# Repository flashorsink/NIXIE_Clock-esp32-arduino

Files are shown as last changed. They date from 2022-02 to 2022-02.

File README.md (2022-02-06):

# NIXIE_Clock-esp32-arduino
使用esp32，8管，自动休眠、氛围灯、休眠和唤醒动画、音乐闹钟、基于Blinker的蓝牙控制  

<p float="left">
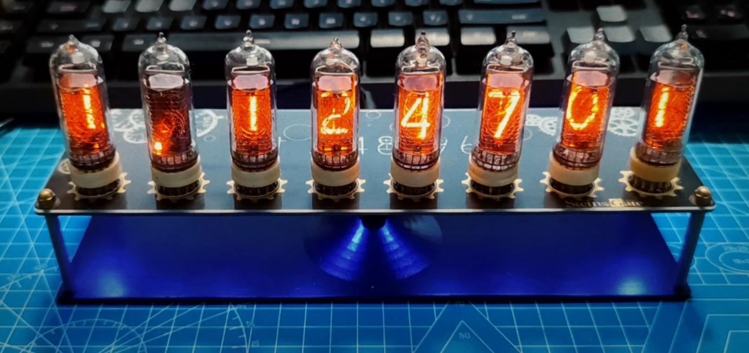
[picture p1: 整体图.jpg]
  
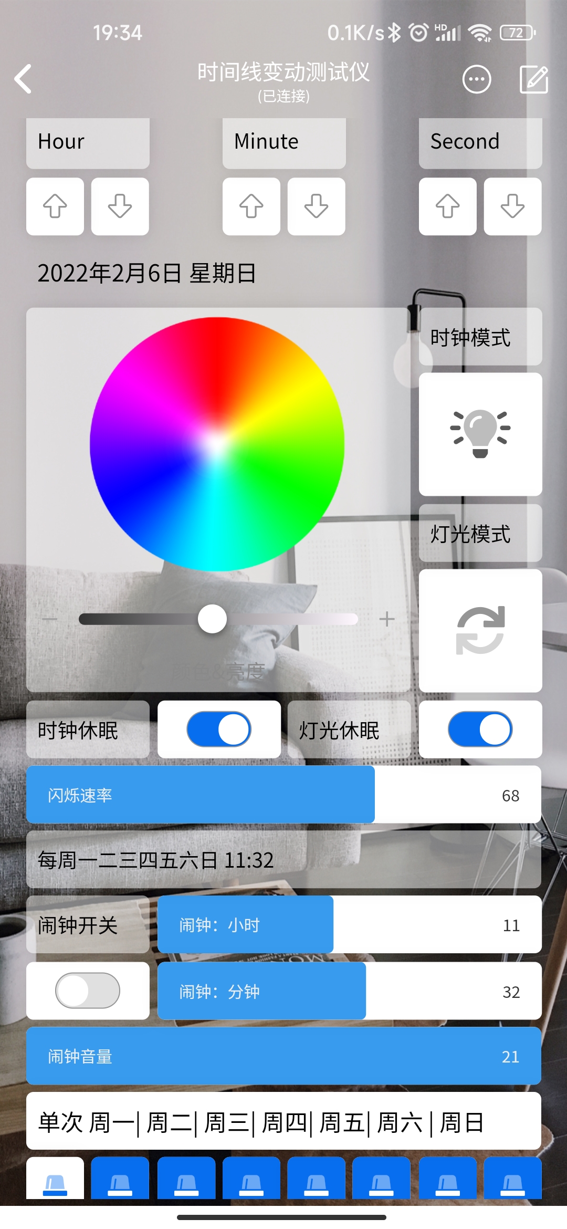
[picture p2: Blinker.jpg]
   
</p>

演示视频https://www.bilibili.com/video/BV1Kr4y1h7Qn/

## 程序

本程序使用esp32 arduino，请使用1.0.6版本，2.0.0及以上版本不兼容无法编译

有两处需要修改部分参见esp32代码libraries文件夹中的说明

各项设置断电后仍会保存

闹钟只支持mp3文件放在sd卡根目录下，可放置多个音乐，每一次响铃会改变歌曲

## PCB

全触摸设计，正面盖板没有开孔，电源口居中，辉光管可插拔设计便于移动和更换。

音频芯片TQFN不易焊接，制作部分用了嘉立创SMT，库中有此芯片的装贴。

## 亚克力

亚克力盖板厚度应小于1mm，否则会影响触摸按键效果

## 底座

底座为3D打印，需要一定精度打印M3螺纹，铜柱高度为40mm

## Blinker

APP蓝牙控制，使用方式在Blinker文件夹中说明

## 操作
各项设置与闹钟时间断电后仍会保留
触摸包含两个控制触摸按键和一个电源触摸按键
1. 短按：设置分钟
2. 长按：设置小时
3. 同时短按：改变时钟模式，四种模式包括时钟显示、时间线时钟显示和时间线随机显示
4. 同时长按：改变灯光模式，包括单色显示、呼吸、渐变、七彩，切换和唤醒都有过渡动画
5. 当闹铃响起时触摸任意一个控制触摸按键都将关闭闹铃

## 注意安全
辉光管使用170v电压，虽然使用的是12VDC转170VDC电流较小并设计了自恢复保险丝，但仍需要注意用电安全，不要触摸辉光钟引脚及PCB底面。

## 感谢
https://github.com/zer0pwned/NixieTubeClock 提供了最初版本的灵感，并使用了其中的辉光插座、时钟芯片和继电器的元件库

https://github.com/Sadudu/MAX1771 提供了12V-170V DC-DC升压电路，经测试输出电容改为电解电容可避免啸叫

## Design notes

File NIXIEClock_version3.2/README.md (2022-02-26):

## esp32 为 esp32-wroom-32(4MB) esp32-wroom-32D也可以，辉光管为in-14
## TP1是170V升压电路的使能，为了测试其他元件时断开使用的，使用时需焊起来
## BOM添加说明：L3与L4用焊锡连通，C33和C34不焊接。此为预留滤波电路，经过测试可以不使用
## SD卡用作闹钟音乐，可放置多首歌每次响铃会切换，仅支持mp3
## 烧录指南
<p float="left">
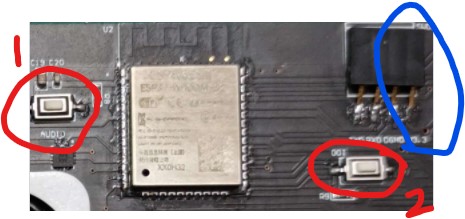
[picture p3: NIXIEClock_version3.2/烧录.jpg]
  
</p>

1. 通电烧录时使用usb转串口连接RXD、TXD、GND三线并给总电源通电，并打开总电源触摸开关，蓝圈的3.3V不使用

2. 红圈1为esp32的使能，2为esp32的IO0，烧录时先同时按下按键1和按键2，然后先松开按键2再松开按键1，此时esp32进入烧录模式

3. 烧录
 
4. 烧录完成后按按键1并松开，程序运行

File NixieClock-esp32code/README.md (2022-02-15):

## 22.2.15更新
  使用多天后发现有触摸误触发的可能，更新每天晚上三点会刷新触摸按键数值避免误触发，触摸触发值+1
  blinker闹钟时间反馈格式优化
## 烧录时需选择Huge APP模式上传，否则会报容量不足的错

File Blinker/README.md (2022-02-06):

# APP使用方法

1. 下载[Blinker app](https://diandeng.tech/doc/app-download)，制作时使用的是2.5.7版本
2. 注册登录
3. 确保辉光钟已开启
4. 点击右上角加号-独立设备-蓝牙接入-选择你的设备点击接入
5. 在设备界面内，点击右上角三点-界面配置-将“Blinker界面配置”文件中的全部复制粘贴-更新配置
6. 更新配置后界面不会立刻改变，退出到所有设备重新打开即可

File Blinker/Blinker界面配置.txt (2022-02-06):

{¨config¨{¨headerColor¨¨transparent¨¨headerStyle¨¨dark¨¨background¨{¨img¨¨assets/img/bg/f1.jpg¨¨isFull¨»}}¨dashboard¨|{¨type¨¨ran¨¨t0¨¨闹钟音量¨¨clr¨¨#389BEE¨¨max¨¤L¨min¨É¨bg¨É¨cols¨Ñ¨rows¨Ê¨key¨´v´´x´É´y´¤F¨speech¨|÷¨lstyle¨Ì}{ßA¨btn¨¨ico¨¨fal fa-arrow-alt-up¨¨mode¨ÊßC¨文本1¨¨t1¨¨文本2¨ßIÉßJÊßKÊßL¨su¨´x´Ï´y´ËßM|÷ßNÍ}{ßAßOßP¨fal fa-arrow-alt-down¨ßRÊßCßSßTßUßIÉßJÊßKÊßL¨hd¨´x´Ê´y´ËßM|÷ßNÍ}{ßAßOßPßQßRÊßCßSßTßUßIÉßJÊßKÊßL¨hu¨´x´É´y´ËßM|÷ßNÍ}{ßAßOßPßWßRÊßCßSßTßUßIÉßJÊßKÊßL¨md¨´x´Í´y´ËßM|÷ßNÍ}{ßAßOßPßQßRÊßCßSßTßUßIÉßJÊßKÊßL¨mu¨´x´Ì´y´ËßM|÷ßNÍ}{ßAßOßPßWßRÊßCßSßTßUßIÉßJÊßKÊßL¨sd¨´x´Ð´y´ËßM|÷ßNÍ}{ßA¨tex¨ßC¨Hour¨ßTßU¨size¨¤EßIÊßP´´ßJËßKÊßLßT´x´É´y´ÊßM|÷}{ßAßcßC¨Minute¨ßTßUße¤EßIÊßP´´ßJËßKÊßL¨t2¨´x´Ì´y´ÊßM|÷}{ßAßcßC¨Second¨ßTßUße¤EßIÊßP´´ßJËßKÊßL¨t3¨´x´Ï´y´ÊßM|÷}{ßAßOßP¨fad fa-sync¨ßRÊßC´´ßTßUßIÉßJËßKËßL¨rm¨´x´Ï´y´ÑßM|÷ßNÉ}{ßAßcßC¨时钟休眠¨ßTßUße¤EßIÊßP´´ßJËßKÊßL¨tex-cjz¨´x´É´y´¤AßM|÷}{ßAßOßP¨fal fa-power-off¨ßRÊßCßSßTßUßIÉßJËßKÊßL¨as¨´x´É´y´¤EßM|÷ßNÌßE¨#076EEF¨}{ßAßOßP¨fad fa-toggle-on¨ßRÊßCßSßTßUßIÉßJËßKÊßL¨sw¨´x´É´y´ÉßM|÷ßNÌ}{ßAßcßC¨更改日期/时间¨ßTßUße¤EßIËßP´´ßJÍßKÊßL¨tex-hj4¨´x´Ë´y´ÉßM|÷ßNÊ}{ßAßcßC´´ßTßUße¨16¨ßIËßP´´ßJÑßKÊßL´d´´x´É´y´ÌßM|÷ßNÎ}{ßAßcßC¨闹钟开关¨ßTßUße¤EßIÊßP´´ßJËßKÊßL¨tex-eyf¨´x´É´y´¤DßM|÷ßNÉ}{ßAßcßC¨灯光休眠¨ßTßUße¤EßIÊßP´´ßJËßKÊßL´´´x´Í´y´¤AßM|÷}{ßAßOßPßnßRÊßC¨自动休眠¨ßTßUßIÉßJËßKÊßL¨sc¨´x´Ë´y´¤AßM|÷ßNÌßEßp}{ßAßOßP¨fad fa-siren¨ßRÉßCßSßTßUßIÉßJÊßKÊßL´w´´x´Ì´y´¤HßM|÷ßNÍßEßp}{ßAßOßPß10ßRÉßC´周一´ßTßUßIÉßJÊßKÊßL´f´´x´Î´y´¤HßM|÷ßNÍßEßp}{ßAßOßPß10ßRÉßCßSßTßUßIÉßJÊßKÊßL´T´´x´Í´y´¤HßM|÷ßNÍßEßp}{ßAßOßPß10ßRÉßCßSßTßUßIÉßJÊßKÊßL´t´´x´Ë´y´¤HßM|÷ßNÍßEßp}{ßAßOßPß10ßRÉßC´7´ßTßUßIÉßJÊßKÊßL´S´´x´Ð´y´¤HßM|÷ßNÍßEßp}{ßAßOßPß10ßRÉßCßSßTßUßIÉßJÊßKÊßL´m´´x´Ê´y´¤HßM|÷ßNÍßEßp}{ßAßOßPß10ßRÉßCßSßTßUßIÉßJÊßKÊßL´s´´x´Ï´y´¤HßM|÷ßNÍßEßp}{ßAßBßC¨闹钟：小时¨ßEßFßG¤OßHÉßIÉßJÏßKÊßL´ah´´x´Ë´y´¤DßM|÷ßNÎ}{ßAßBßC¨闹钟：分钟¨ßEßFßG¤xßHÉßIÉßJÏßKÊßL´am´´x´Ë´y´¤EßM|÷ßNÎ}{ßAßcßC¨单次 周一|  周二|  周三| 周四|  周五| 周六 | 周日   ¨ßTßUßeßußIÉßP´´ßJÑßKÊßL¨tex-vka¨´x´É´y´¤GßM|÷ßNÎ}{ßAßOßP¨fad fa-lightbulb-on¨ßRÉßC´´ßTßUßIÉßJËßKËßL´cm´´x´Ï´y´ÎßM|÷ßNÉßE¨#595959¨}{ßAßBßC¨闪烁速率¨ßEßFßG¢1cßHÊßIÉßJÑßKÊßL´rs´´x´É´y´¤BßM|÷ßNÌ}{ßAßcßC´´ßT´´ße¤EßIÊßP´´ßJÑßKÊßL´al´´x´É´y´¤CßM|÷ßNÎ}{ßAßOßPß10ßRÊßCßSßTßUßIÉßJÊßKÊßL´ss´´x´É´y´¤HßM|÷ßNÍßEßp}{ßA¨col¨ßC¨颜色&亮度¨ßEßFßIÊßJÏßKÏßL¨RGB¨´x´É´y´ÍßM|÷}{ßAßOßPßnßRÊßCßSßTßUßIÉßJËßKÊßL´ls´´x´Ï´y´¤AßM|÷ßNÌßEßp}{ßAßcßC¨灯光模式¨ßTßUße¤EßIÊßP´´ßJËßKÊßL¨tex-r4w¨´x´Ï´y´ÐßM|÷}{ßAßcßC¨时钟模式¨ßTßUße¤EßIÊßP´´ßJËßKÊßL¨tex-66x¨´x´Ï´y´ÍßM|÷}÷¨actions¨|¦¨cmd¨¦¨switch¨‡¨text¨‡´on´¨打开?name¨¨off¨¨关闭?name¨—÷¨triggers¨|{¨source¨ß1H¨source_zh¨¨开关状态¨¨state¨|´on´ß1K÷¨state_zh¨|´打开´´关闭´÷}÷}

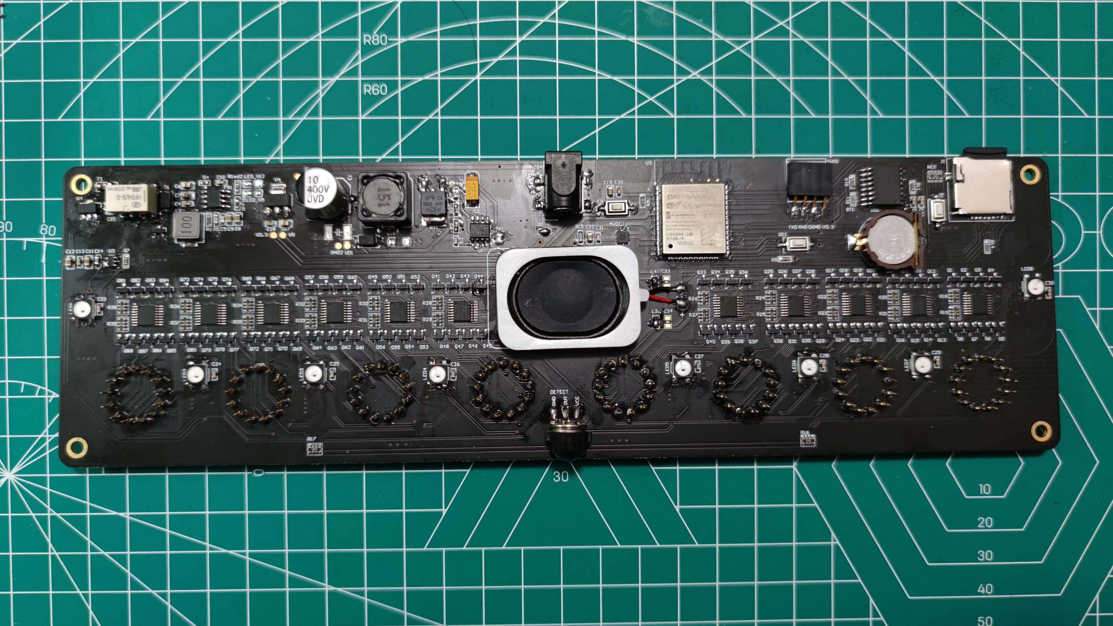
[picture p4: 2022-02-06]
背面图_1.jpg

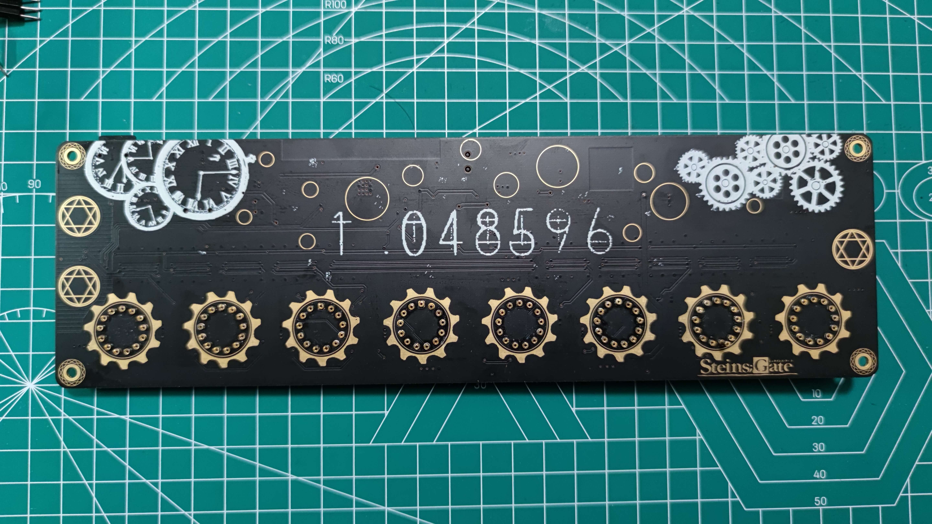
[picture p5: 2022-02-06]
正面图_1.jpg

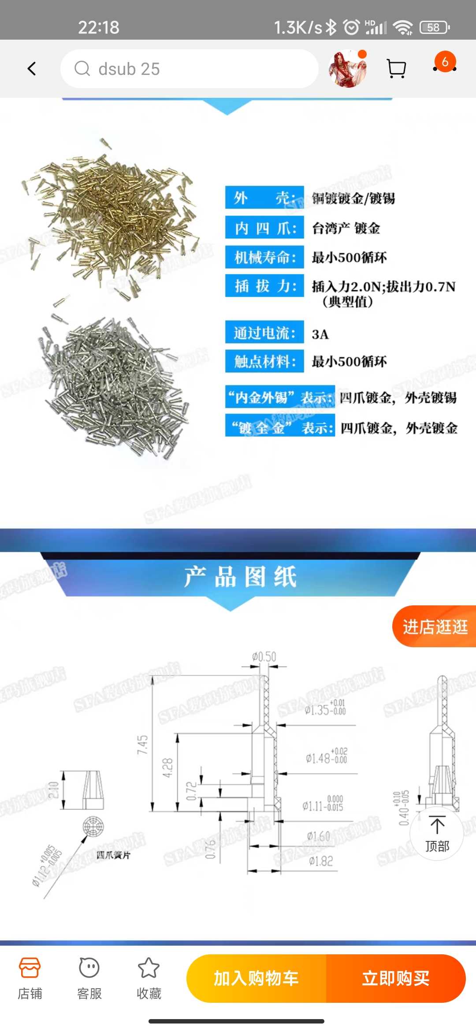
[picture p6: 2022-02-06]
NIXIEClock_version3.2/镀金插针_需要13x8x2=208个.jpg

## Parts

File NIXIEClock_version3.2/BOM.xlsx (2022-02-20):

Comment | Description | Designator | Footprint | LibRef | Quantity
MAX98357 | 音频芯片 | AUDIO | QFN16_3X3 | MAX98357 | 1
beep | 4Ω 3W 25*35*6.6 | beep | BEEP2 | beep | 1
CR1220 holder | 电池底座 | BT1 | BAT1220 | BATTERY | 1
100u/16v | 贴片钽电容 | C2 | CD C(6032) | C-CD | 1
0.1uF | 无极性贴片电容 | C3, C4, C10, C13, C18, C20, C21, C22, C23, C24, C25, C26, C27, C28, C29, C30, C31 | C 0603_L | C | 17
100pF | 无极性贴片电容 | C5 | C 0603_L | C | 1
10uF | 无极性贴片电容 | C6, C7, C11, C12, C15, C17, C19, C32 | C 0805_L | C | 8
22uF | 无极性贴片电容 | C8, C9 | C 0805_L | C | 2
20pf | 无极性贴片电容 | C14 | C 0603 | C | 1
220pF（不焊接！） | 无极性贴片电容 | C33, C34 | C 0805_L | C | 2
3.5*1.3 | 低压电源接口 | CON1 | DC-050 | P-DC | 1
1N4007(M7) | 1 Amp General Purpose Rectifier | D1 | 1N4007W | Diode 1N4007 | 1
RDB223 | 数字热释电传感器 | DETECT | 红外热释电 | UGN3503 | 1
DS3231 | 时钟芯片 | DS1 | SOP16_75MM | DS3231 | 1
10uF/400V | 贴片电解电容 | E1 | CM F(10*10.2) | C-CM | 1
SW-PB | Switch | EN, IO0, S1 | 贴片按键（红头） | SW-PB | 3
3A | 贴片保险丝 | F1 | FU 1206 | FU | 1
FR9886 2.5A | 2.5A DC-DC | FR1 | SOP8_N | FR9833 | 1
74HC595 | 8位移位寄存器 | IC1, IC2, IC3, IC4, IC5, IC6, IC7, IC8, IC9, IC10, IC11 | TSSOP16_N | 74HC595 | 11
Micro SD | Micro SD卡 | J1 | Micro SD | Micro SD | 1
150uf | 功率屏蔽电感 | L1 | CDRH127 | L-CDRH | 1
10uH | 功率屏蔽电感 | L2 | L-SMD-0630 | L-CDRH | 1
10uH(直接用焊锡连通！) | 小功率贴片电感 | L3, L4 | L 0805_L | L | 2
WS2812B | LED | LED1, LED2, LED3, LED4, LED5, LED6, LED7, LED8 | WS2812B-5050 | WS2812B | 8
绿色 | 贴片LED(测试使用) | LED_V5 | LED 0805G | LED-SMD | 1
蓝色 | 贴片LED(测试使用) | LED_V12 | LED 0805B | LED-SMD | 1
MMBTA42 | 高频放大-NPN型 | Q1, Q2, Q3, Q4, Q5, Q6, Q7, Q8, Q9, Q10, Q11, Q12, Q13, Q14, Q15, Q16, Q17, Q18, Q19, Q20, Q21, Q22, Q23, Q24, Q25, Q26, Q27, Q28, Q29, Q30, Q31, Q32, Q33, Q34, Q35, Q36, Q37, Q38, Q39, Q40, Q41, Q42, Q43, Q44, Q45, Q46, Q47, Q48, Q49, Q50, Q51, Q52, Q53, Q54, Q55, Q56, Q57, Q58, Q59, Q60, Q61, Q62, Q63, Q64, Q65, Q66, Q67, Q68, Q69, Q70, Q71, Q72, Q73, Q74, Q75, Q76, Q77, Q78, Q79, Q80, Q81, Q82, Q83, Q84, Q85, Q86, Q87, Q88 | SOT23-3N | 8050-SMD | 88
S9013 | NPN Bipolar Transistor | QN | SOT23-3L | NPN | 1
IRFR224 | N沟场效应管 | QT1 | TO252 | IRF3710 | 1
0 | 贴片电阻 | R0 | R 0603 | R | 1
50m | 贴片电阻 | R1 | R 0805_L | R | 1
1.8M/0603/1% | 贴片电阻 | R2 | R 0603 | R | 1
16K/0603/1% | 贴片电阻 | R3 | R 0603 | R | 1
100K | 贴片电阻 | R4 | R 0603_L | R | 1
44.2K | 贴片电阻 | R5 | R 0603 | R | 1
10K | 贴片电阻 | R6, R8, R9, R12, R14 | R 0603 | R | 5
10k | 贴片网络排阻 | R13, R10, R11 | RCA-8P4R-0603 | R-8P4R | 1
1M | 贴片电阻 | R15 | R 0603 | R | 1
20K | 贴片网络排阻 | R16, R17 | RCA-8P4R-0603 | R-8P4R | 2
1k | 贴片网络排阻 | R18, R19, R20, R21, R22, R23, R24, R25, R26, R27, R28, R29, R30, R31, R32, R33, R34, R35, R36, R37, R38, R39, R7 | RCA-8P4R-0603 | R-8P4R | 22
RFD4/5V | 继电器 | Relay1 | HFD4 | Relay | 1
180 | 贴片电阻 | Rled1 | R 0603 | R | 1
820 | 贴片电阻 | Rled2 | R 0603 | R | 1
Header 4 | Header, 4-Pin | SWD1 | HDR2.54-M-WS-4P | Header 4 | 1
铜柱 | 40mm | T0, T1, T2, T3 | 铜柱_六芒星 | 铜柱 | 4
MAX1771 | 170V升压芯片 | U1 | SOP8_M | MAX1771 | 1
ESP32-WROOM-32D | IC: SoC; GPIO, I2C, I2S, IR, SD, SDIO, SPI, UART; 2.7Ã·3.6VDC; 20dBm | U2 | *MODULE_ESP32-WROOM-32D | ESP32-WROOM-32D | 1
ttp223 | 触摸芯片 | U3 | SOT23-6L | ttp223 | 1
HT7150 | LDO线性稳压芯片 | U4 | SOT89_M | HT71xx | 1
AMS1117-3V3 | 三端稳压芯片 | V4 | SOT223_N | AMS1117 | 1
>1A 400V（RS1G） | 肖特基二极管 | VD1 | SMA | （RS1G） | 1

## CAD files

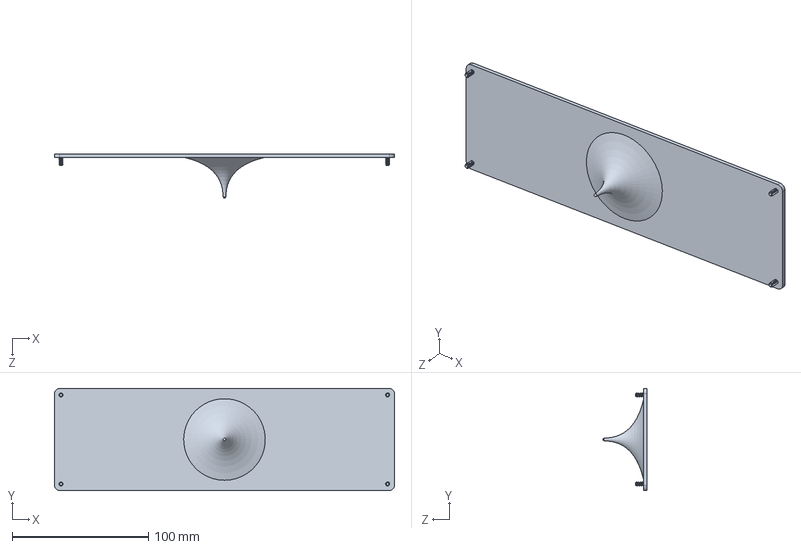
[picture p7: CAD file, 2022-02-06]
亚克力盖板及底座模型/底座.SLDPRT
250.0 x 75.0 x 32.5 mm

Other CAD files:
亚克力盖板及底座模型/亚克力盖板.DWG
亚克力盖板及底座模型/底座.STL

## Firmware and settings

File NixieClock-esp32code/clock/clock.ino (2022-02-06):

//#define TEST
#ifdef TEST
    #define SLEEPTIME 100
#else
#define SLEEPTIME 1200
#endif
#include<string.h>
#include<stdio.h>
char str[50];
char str2[4];
/////////////////// data storage configuration/////////////////////////////
#include <Preferences.h>
Preferences STORGE; 
///////////////////DS3231 configuration///////////////////////
#include <Wire.h> // must be included here so that Arduino library object file references work
#include <RtcDS3231.h>
#define RtcSquareWavePin 5 //alarm pin
#define countof(a) (sizeof(a) / sizeof(a[0]))
RtcDS3231<TwoWire> Rtc(Wire);//SDA21 SCL22
volatile bool interruptFlag = false;//alarm interrupt
RtcDateTime oldtime;
RtcDateTime now;
bool flashnow=true;
///////////////////Scan configuration/////////////////////
#define SCAN  34//18
//////////////////Ticker clock configuration///////////////////////////
#include <Ticker.h>
Ticker tickerclock;
Ticker tickerchange;
volatile bool timetoflash = false;
bool clockflag=false;
volatile int clock_counter=0;
bool scanhuman=true;
///////////////////RGB configuration///////////////////////////
volatile int8_t gradient=0;//0 means nothing;1 means changemode-1 light down;2 means changemode light up;3 means changemode light down;
#include "Freenove_WS2812_Lib_for_ESP32.h"
#define LEDS_COUNT  8 //how many led 
#define LEDS_PIN  12
#define CHANNEL   0
Freenove_ESP32_WS2812 strip = Freenove_ESP32_WS2812(LEDS_COUNT, LEDS_PIN, CHANNEL, TYPE_GRB);
//bool rgb_switch=false;
bool rgb_sleep=false;
uint8_t color_r=0,color_g=0,color_b=0,bright=0;
int8_t RGBmode=1;
bool RGBflag=false;
Ticker tickerRGB;
//////////////////Touch configuration//////////////////////
Ticker tickertouch;
int8_t gottouch1=0;
int8_t gottouch2=0;
#define TOUCHPAD_1 T3//gpio13
#define TOUCHPAD_2 T4//gpio15

int8_t level_1; // 
int8_t level_2; // 

#define TOUCH1 1
#define TOUCH2 2
#define BOTHTOUCH_SHORT 3
#define BOTHTOUCH_LONG 4
#define TOUCH1_LONG 5
#define TOUCH2_LONG 6
bool touch1=false;
bool touch2=false;
bool touchdone=false;//indicate if finger has moed away 
int  touch=0; //1:button1 2:botton2 3:botton 1and2 short 4:botton 1 and 2 long
///////////////////music configuration///////////////////////
#include "Audio.h"
#include "SPI.h"
#include "SD.h"
#include "FS.h"
#define SD_CS         4
#define SPI_MOSI      23
#define SPI_MISO      19
#define SPI_SCK       18
#define I2S_DOUT      25
#define I2S_BCLK      27
#define I2S_LRC       26
Audio audio;
char songname[20][50];
int songnumber=0;
volatile bool songflag=false;
bool songon=false;
//////////////////////74hc595 confifuration////////////////////
unsigned char LED_0F[] = 
    {
        B10000000,B00000000,//0
    	B00000000,B01000000,//1
        B00000000,B10000000,//2
        B00000001,B00000000,//3
        B00000010,B00000000,//4
        B00000100,B00000000,//5 
        B00001000,B00000000,//6
        B00010000,B00000000,//7
        B00100000,B00000000,//8
        B01000000,B00000000,//9
        B00000000,B00100000,//.
        B00000000,B00000000,//none
        B10000000,B00000000,//0
    	B00000000,B01000000,//1
        B00000000,B10000000,//2
        B00000001,B00000000,//3
        B00000010,B00000000,//4
        B00000100,B00000000,//5 
        B00001000,B00000000,//6
        B00010000,B00000000,//7
        B00100000,B00000000,//8
        B01000000,B00100000,//9+.
    };
#define NONE 11
#define DOT 10
    unsigned char LED[8]={11,11,11,11,11,11,11,11};//cache for 8 figures initial none
    int SCLK = 14;
    int RCLK = 17;
    int DIO = 16; 
int8_t clockmode=1;
//////////////////////ALARM ////////////////////////////////
   bool alarmswitch,alarmsingle;
   bool day[7];
   int8_t alarmh,alarmm;
//////////////////////blinker configuration/////////////////////

#define BLINKER_BLE  
#define BLINKER_PRINT Serial
#include "Blinker.h"
int32_t voice=5;
bool switchset=0;
BlinkerRGB RGB("RGB");
//BlinkerButton RGBS_SWITCH("cs");
BlinkerButton RGBS_SLEEP("ls");
BlinkerButton HOUR_UP("hu");
BlinkerButton HOUR_DOWN("hd");
BlinkerButton MINUTE_UP("mu");
BlinkerButton MINUTE_DOWN("md");
BlinkerButton SECOND_UP("su");
BlinkerButton SECOND_DOWN("sd");
BlinkerButton SWITCH("sw");
BlinkerButton SCANHUMAN("sc");
BlinkerButton CLOCKMODE("cm");
BlinkerText TEXT1("t1");
BlinkerText TEXT2("t2");
BlinkerText TEXT3("t3");
BlinkerText DATE("d");
BlinkerSlider VOICE("v");
BlinkerButton RGBMODE("rm");
BlinkerSlider RGBSPEED("rs");
BlinkerButton MON("m");
BlinkerButton TUE("t");
BlinkerButton WED("w");
BlinkerButton THU("T");
BlinkerButton FRI("f");
BlinkerButton SAT("s");
BlinkerButton SUN("S");
BlinkerButton ALARMSWITCH("as");
BlinkerButton ALARMSINGLE("ss");
BlinkerText ALARM("al");
BlinkerSlider ALARMH("ah");
BlinkerSlider ALARMM("am");

int8_t rgbspeed=15;
bool touchbegin=false;
void setup () 
{
 ///////////////////////Serial Setup/////////////////////////////    
#ifdef TEST   
    Serial.begin(115200); 
#endif
////////////////////////////////////////////////////////////////////
    randomSeed(analogRead(35));
/////////////////////////Touchpad Setup/////////////////////////////
    int8_t TOUCHLEVEL_1[9]; // 
    int8_t TOUCHLEVEL_2[9]; // 
    for(int8_t i=8;i>=0;i--)
    {
        TOUCHLEVEL_1[i]=touchRead(TOUCHPAD_1);
        TOUCHLEVEL_2[i]=touchRead(TOUCHPAD_2);
    }
    int8_t temp;
    for(int8_t i=8;i>=1;i--)
    {
        for(int8_t j=0;j<=i-1;j++)
        {
            if(TOUCHLEVEL_1[j]>=TOUCHLEVEL_1[j+1]){temp=TOUCHLEVEL_1[j+1];TOUCHLEVEL_1[j+1]=TOUCHLEVEL_1[j];TOUCHLEVEL_1[j]=temp;}
            if(TOUCHLEVEL_2[j]>=TOUCHLEVEL_2[j+1]){temp=TOUCHLEVEL_2[j+1];TOUCHLEVEL_2[j+1]=TOUCHLEVEL_2[j];TOUCHLEVEL_2[j]=temp;}
        }
    }
    level_1=TOUCHLEVEL_1[4];
    level_2=TOUCHLEVEL_2[4];


#ifdef TEST
    Serial.print("TOUCHLEVEL1=");  for(int8_t i=8;i>=0;i--) {Serial.print(TOUCHLEVEL_1[i]);} Serial.println("");
    Serial.print("TOUCHLEVEL2=");  for(int8_t i=8;i>=0;i--) {Serial.print(TOUCHLEVEL_2[i]);} Serial.println("");
    Serial.print("level1=");        Serial.println(level_1);
    Serial.print("level2=");        Serial.println(level_2);
#endif
touchAttachInterrupt(TOUCHPAD_1, GotTouch_1, level_1-5);
touchAttachInterrupt(TOUCHPAD_2, GotTouch_2, level_2-5);
   
    
/////////////////////HC595///////////////////////////////////////
    pinMode(SCLK,OUTPUT);
    pinMode(RCLK,OUTPUT);
    pinMode(DIO,OUTPUT);
    digitalWrite(RCLK,LOW);
    digitalWrite(RCLK,HIGH);
    for(int i=0;i<=7;i++) LED[i]=NONE;LED_Display();
///////////////////storage setup////////////////////////////
    STORGE.begin("mynamespace");
    scanhuman=STORGE.getBool("scanhuman",true);
//   rgb_switch=STORGE.getBool("rgb_switch",false);
    rgb_sleep=STORGE.getBool("rgb_sleep",false);
    color_r=STORGE.getUChar("color_r",255);
    color_g=STORGE.getUChar("color_g",255);
    color_b=STORGE.getUChar("color_b",255);
    bright=STORGE.getUChar("bright",50);
    RGBmode=STORGE.getUChar("RGBmode",1);
    voice=STORGE.getUInt("voice",5);
    rgbspeed=STORGE.getUChar("rgbspeed",15);
    clockmode=STORGE.getUChar("clockmode",1);
    if(clockmode==4) clockmode=1;
    day[1]=STORGE.getBool("day[1]",false);
    day[2]=STORGE.getBool("day[2]",false);
    day[3]=STORGE.getBool("day[3]",false);
    day[4]=STORGE.getBool("day[4]",false);
    day[5]=STORGE.getBool("day[5]",false);
    day[6]=STORGE.getBool("day[6]",false);
    day[0]=STORGE.getBool("day[0]",false);
    alarmswitch=STORGE.getBool("alarmswitch",false);
    alarmh=STORGE.getUChar("alarmh",10);
    alarmm=STORGE.getUChar("alarmm",30);
    alarmsingle=STORGE.getBool("alarmsingle",false);

///////////////////////DS3231 setup/////////////////////////////
    Rtc.Begin();
    RtcDateTime now ;
    now = Rtc.GetDateTime();
    oldtime=now;
    Rtc.Enable32kHzPin(false);
    Rtc.SetSquareWavePin(DS3231SquareWavePin_ModeAlarmOne); //how many alarm you want, up to 2
/////////////////////RGB setup////////////////////////////////////
    strip.begin();
/////////////////////RGB test/////////////////////////////////////
    strip.setBrightness(0);  
    strip.setAllLedsColorData(0,0,0);
    strip.show();
    if (RGBmode!=5) tickerRGB.attach_ms(110-rgbspeed,RGBchange);
#ifdef TEST
    Serial.print("110-rgbspeed:");
    Serial.println(110-rgbspeed);
#endif 
////////////////////humanscan setup////////////////////////////////    
    pinMode(SCAN, INPUT_PULLDOWN);
    attachInterrupt(digitalPinToInterrupt(SCAN), InterruptServiceRoutine_scanhuman, RISING);
    if(scanhuman)tickerclock.attach_ms(100,clocksever,SLEEPTIME); 
   
///////////////////music setup/////////////////////////////////
    pinMode(SD_CS, OUTPUT);      
    digitalWrite(SD_CS, HIGH);
    SPI.begin(SPI_SCK, SPI_MISO, SPI_MOSI);
    SPI.setFrequency(10000000);
    SD.begin(SD_CS);
    File dir=SD.open("/");
     while (true)
    {
 
        File entry = dir.openNextFile();
        if (!entry)
        {
            // 如果没有文件则跳出循环
            break;
        }
        if(strstr(entry.name(), ".mp3")!=NULL)
        {
            strcpy(songname[songnumber],entry.name());
            songnumber++;
        }
        entry.close();
    }
    dir.close();
    #ifdef TEST
        Serial.println("MUSIC LIST:");
        for(int i=0;i<songnumber;i++)// show music list 
        {
            Serial.println(songname[i]);
        }
    #endif
    audio.setPinout(I2S_BCLK, I2S_LRC, I2S_DOUT);
    audio.setVolume(voice); // 0...21   
 
/////////////////start sceen//////////////////////////////////
    startshow();

///////////////////blinker/////////////////////
    Blinker.begin();
    Blinker.attachHeartbeat(heartbeat); 
    RGB.attach(rgb_callback);
 // RGBS_SWITCH.attach(rgbswitch_callback);
    RGBS_SLEEP.attach(rgbsleep_callback);
    RGBMODE.attach(rgbmode_callback);
    HOUR_UP.attach(hourup_callback);
    HOUR_DOWN.attach(hourdown_callback);
    MINUTE_UP.attach(minuteup_callback);
    MINUTE_DOWN.attach(minutedown_callback);
    SECOND_UP.attach(secondup_callback);
    SECOND_DOWN.attach(seconddown_callback);
    SWITCH.attach(switch_callback);
    SCANHUMAN.attach(scanhuman_callback);
    VOICE.attach(voice_callback);
    RGBSPEED.attach(rgbspeed_callback);
    CLOCKMODE.attach(clockmode_callback);
    MON.attach(mon_callback);
    TUE.attach(tue_callback);
    WED.attach(wed_callback);
    THU.attach(thu_callback);
    FRI.attach(fri_callback);
    SAT.attach(sat_callback);
    SUN.attach(sun_callback);
    ALARMH.attach(alarmh_callback);
    ALARMM.attach(alarmm_callback);
    ALARMSWITCH.attach(alarmswitch_callback);
    ALARMSINGLE.attach(alarmsingle_callback);
///////////////////////////////////////////////////
 touch=0;
    touch1=false;
    touch2=false;
    touchbegin=false;
    tickertouch.attach_ms(100,Touchsever);
}


void loop () 
{  
    Blinker.run();
    if(flashnow)
        {
           
            now = Rtc.GetDateTime();flashnow=false;
        }
    if(clockflag){clockchange();clockflag=false;}
    if(RGBflag){RGBsever(false);RGBflag=false;}
    Clockshow();
    Alarmed();
    Touchpocess();  
    Storge();
}


bool changevoice=false,changergb=false,changealarmh=false,changealarmm=false,changergb2=false;
void Storge()
{
    static int32_t i=0;
    if(changevoice||changergb||changealarmh||changealarmm){i++;}
    if(i>700000)
    {
        i=0;
        if(changevoice)
        {
                {STORGE.putUInt("voice",voice);changevoice=false;
                #ifdef TEST 
                    Serial.println("change1!");
                #endif
                }
        }
        if(changergb)
        {
                {STORGE.putUChar("rgbspeed",rgbspeed);changergb=false;
                #ifdef TEST 
                    Serial.println("change2!");
                #endif
                }
        }
        if(changealarmh||changealarmm)
        {
            showalarm();
            if(changealarmh)
                {STORGE.putUChar("alarmh",alarmh);changealarmh=false;
                #ifdef TEST 
                    Serial.println("change3!");
                #endif
                }
            if(changealarmm)
                {STORGE.putUChar("alarmm",alarmm);changealarmm=false;
                #ifdef TEST 
                    Serial.println("change4!");
                #endif
                } 
        }     
        if(changergb2)
        {
            STORGE.putUChar("color_r",color_r);
            STORGE.putUChar("color_g",color_g);
            STORGE.putUChar("color_b",color_b);
            STORGE.putUChar("bright",bright);
            #ifdef TEST 
            Serial.println("changergb!");
            #endif
        }   
    }    
}
bool clockgradient=false;bool clockgradienton=false;
void InterruptServiceRoutine_scanhuman()
{   
    #ifdef TEST
    Serial.println("trigger!!");
    #endif
   // Clockshow(); overflow!may beacause of i2c
    clock_counter=0;
    
    if(scanhuman && clockmode!=3) 
    {
        timetoflash=true;   
        if(!tickerclock.active()) 
        {
             clockgradient=true; 
             clockgradienton=true; 
             tickerclock.attach_ms(100,clocksever,SLEEPTIME);
             if(!tickerchange.active()){ tickerchange.attach_ms(50,clock2);}
        }
    }
}

volatile bool closeflag=false;
int8_t count10=9;

void Clockshow()
{
    if(closeflag && !tickerchange.active()) 
    {
        timetoflash=false;
        Serial.println("close0");
        closeflag=false;
        clockgradient=true;
        clockgradienton=false;
        if(!tickerchange.active()) tickerchange.attach_ms(50,clock2);
        // for(int i=0;i<=7;i++) 
        //     LED[i]=NONE;LED_Display();
        if(rgb_sleep)
        {  
            gradient=3;
            if(!tickerRGB.active()) tickerRGB.attach_ms(110-rgbspeed,RGBchange);

            // strip.setBrightness(0);  
            // strip.setAllLedsColorData(0,0,0);
            // strip.show();
            // if(tickerRGB.active())tickerRGB.detach();
        }
    }
    
        if(timetoflash==true||!scanhuman||clockmode==3||songon)
        {
            if(rgb_sleep && !tickerRGB.active()){gradient=2; tickerRGB.attach_ms(110-rgbspeed,RGBchange);}
            timetoflash=false;
            if(oldtime!=now)
                {
                count10++;
                if (count10>10) count10=10;
                oldtime=now;
                printDateTime();
                }
        }
    
    
}
void clocksever(int counter)
{
        timetoflash=true;
        if(scanhuman&&clockmode!=3&&clockmode!=4)
        {
            bool scanhumanflag;
            scanhumanflag=digitalRead(SCAN);
            if (scanhumanflag==true)
            {            
                clock_counter=0;
            }    
            else {
                clock_counter++;    
                if(clock_counter>=counter)//100*100ms=10s
                {
                    clock_counter=0;
                    closeflag=true;
                    // if(!tickerchange.active()) tickerchange.attach_ms(50,clock2);
                    if(tickerclock.active())tickerclock.detach();
                    return;
                }    
            }
        }
}

void printDateTime()
{
    #ifdef TEST
    char datestring[20];
    snprintf_P(datestring, 
            countof(datestring),
            PSTR("%02u/%02u/%04u %02u:%02u:%02u"),
            now.Month(),
            now.Day(),
            now.Year(),
            now.Hour(),
            now.Minute(),
            now.Second() );
    Serial.println(datestring);
    #endif
    tickerchange.attach_ms(50,clock2);
}
void clock2()
{
    clockflag=true;
}

void clockchange()
{   
   
    if(clockgradient)
    {
        static int8_t gradientnumber=0; 
        bool mask[7];
            if(clockmode==1) {mask[7]=true;mask[6]=true;mask[5]=false;mask[4]=true;mask[3]=true;mask[2]=false;mask[1]=true;mask[0]=true;}
            if(clockmode==2) {mask[7]=true;mask[6]=true;mask[5]=true;mask[4]=true;mask[3]=true;mask[2]=true;mask[1]=true;mask[0]=true;}
            if(clockmode==3) {mask[7]=true;mask[6]=true;mask[5]=true;mask[4]=true;mask[3]=true;mask[2]=true;mask[1]=true;mask[0]=true;}
            if(clockmode==4) {mask[7]=false;mask[6]=false;mask[5]=false;mask[4]=false;mask[3]=false;mask[2]=false;mask[1]=false;mask[0]=false;}
            for (int i=0;i<=7;i++)
            {
                if (mask[i]==true) LED[i]=random(10);
            }
            LED_Display();
            gradientnumber++;
            if(gradientnumber>=5)
            {
                gradientnumber=0;
                clockgradient=false;
                if(clockgradienton==false)
                {
                    clockgradienton=true;
                    if(tickerchange.active())tickerchange.detach();
                    for(int i=0;i<=7;i++) 
                    LED[i]=NONE;LED_Display();
                    closeflag=false;
                    return;
                }
            }
            
    }
    else
    {
        static int8_t t=0;
        int8_t x;
        int8_t h1=(now.Hour()/10);int8_t h2=(now.Hour()%10);int8_t m1=(now.Minute()/10); int8_t m2=(now.Minute()%10); int8_t s1=(now.Second()/10); int8_t s2=(now.Second()%10);
        
        if(clockmode==1)
        {
            t++;
            if(s1==0 && s2==0 && t<=8) 
            {LED[7]=random(7)+3+12;LED[6]=random(10)+12;LED[5]=NONE;LED[4]=random(3)+7+12;LED[3]=random(10)+12;LED[1]=random(3)+7+12;LED[0]=random(10)+12;LED[2]=NONE;LED_Display();}
            else if(s2==0 && t<=4) 
            {LED[7]=h1;LED[6]=h2;LED[5]=NONE;LED[4]=m1;LED[3]=m2;LED[1]=random(3)+7;LED[0]=s2;LED[2]=NONE;LED_Display();}
            else 
                {          
                    t=0;  
                    LED[7]=h1;LED[6]=h2;LED[5]=NONE;LED[4]=m1;LED[3]=m2;LED[1]=s1;LED[0]=s2;LED[2]=NONE;LED_Display();
                    if(tickerchange.active())tickerchange.detach();
                }
        }
        if(clockmode==2)
        {
            static int8_t y=0;
            t++;
            if(s2==0 && t<=8) 
            {   x=random(9)+2;if(x==10)x=0;
                LED[7]=x+12;
                LED[6]=random(10);LED[5]=random(7)+3+12;LED[4]=random(10)+12;LED[3]=random(3)+7+12;LED[2]=random(10)+12;LED[1]=random(3)+7+12;LED[0]=random(10)+12;LED_Display();
                if(t==8)
                {if(random(10)==9) y=0;else y=1; }
            }
            else
            
                {          
                    t=0;
                    LED[7]=y;LED[6]=DOT;LED[5]=h1;LED[4]=h2;LED[3]=m1;LED[2]=m2;LED[1]=s1;LED[0]=s2;LED_Display();
                    if(tickerchange.active())tickerchange.detach();
                }
        }
        if(clockmode==3)
        {
        if (count10>=10)
            {   
                t++;
                if(t<=8) { x=random(9)+2;if(x==10)x=0;LED[7]=x;LED[6]=random(10)+12;LED[5]=random(7)+3+12;LED[4]=random(10)+12;LED[3]=random(3)+7+12;LED[2]=random(10)+12;LED[1]=random(3)+7+12;LED[0]=random(10)+12;LED_Display();}
                    else 
                    {   
                    count10=0;      
                    t=0;  
                    if(random(10)==9) x=0;else x=1;  
                    LED[7]=x;LED[6]=DOT;LED[5]=random(10);LED[4]=random(10);LED[3]=random(10);LED[2]=random(10);LED[1]=random(10);LED[0]=random(10);LED_Display();
                    if(tickerchange.active())tickerchange.detach();
                    }
            }
            else{ if(tickerchange.active())tickerchange.detach();}
        }
        if(clockmode==4)
        {
            for (int i=0;i<=7;i++) LED[i]=NONE;
            LED_Display();
            if(tickerchange.active())tickerchange.detach();
        }
    }    
}

void startshow()
{   
    for(int i=0;i<=170;i++)
    {
        for (int j=0;j<=7;j++) LED[j]=random(10);
        LED_Display();
        RGBsever(true);
        delay(18);
    }
    now = Rtc.GetDateTime();
    int8_t h1=(now.Hour()/10);int8_t h2=(now.Hour()%10);int8_t m1=(now.Minute()/10); int8_t m2=(now.Minute()%10); int8_t s1=(now.Second()/10); int8_t s2=(now.Second()%10);
    RGBsever(false); 
    timetoflash=true;    
    clockchange();  
    timetoflash=true; 
}

void LED_OUT(unsigned char LED1,unsigned char LED2)
{
    	unsigned char i;
    	for(i=8;i>=1;i--)
    	{
    		if (LED1&0x80) 
                {
                  digitalWrite(DIO,HIGH);
                 }  
                else 
                {
                  digitalWrite(DIO,LOW);
                }
    		LED1<<=1;
                digitalWrite(SCLK,LOW);
                digitalWrite(SCLK,HIGH);
    	}
        for(i=3;i>=1;i--)
    	{
    		if (LED2&0x80) 
                {
                  digitalWrite(DIO,HIGH);
                 }  
                else 
                {
                  digitalWrite(DIO,LOW);
                }
    		LED2<<=1;
                digitalWrite(SCLK,LOW);
                digitalWrite(SCLK,HIGH);
    	}
}

void LED_Display ()
{
    	unsigned char *led_table;          // 查表指针

    	for(int i=0;i<=7;i++)
        {
            led_table = LED_0F + 2*LED[i];           
    	    LED_OUT(*led_table,*(led_table+1));	
        }	
        digitalWrite(RCLK,LOW);
        digitalWrite(RCLK,HIGH);
}

void RGBchange()
{
    RGBflag=true;
}
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

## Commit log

2022-02-06 Update and rename 使用必看.md to README.md
2022-02-15 Add files via upload
    使用多天后发现有触摸误触发的可能，更新每天晚上三点会刷新触摸按键数值避免误触发，触摸触发值+1
    blinker闹钟时间反馈优化
2022-02-20 添加说明
    L3与L4用焊锡连通，C33和C34不焊接
    [BOM.xlsx]
